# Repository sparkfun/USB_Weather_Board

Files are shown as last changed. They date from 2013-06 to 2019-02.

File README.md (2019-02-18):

# **NOTE: This product has been retired from our catalog. The information contained here is for reference only. No support is guaranteed. For a new version, please check out our [Weather Shield](https://www.sparkfun.com/products/12081).**

*If you are looking for more up-to-date info, please check out some of these resources to see how other users are still hacking and improving on this product.*
* *[SparkFun Forum](https://forum.sparkfun.com/)*
* *[Comments Here on GitHub](https://github.com/sparkfun/USB_Weather_Board/issues)*
* *[IRC Channel](https://www.sparkfun.com/news/263)*

## USB Weather Board [(SEN-10586)](https://www.sparkfun.com/products/10586)

USB Weather Board

SparkFun's USB Weather Board contains sensors that can be used to monitor atmospheric pressure, humidity, temperature, and light level. The board can also be interfaced to wind speed, direction, and rainfall sensors available separately from Sparkfun.

Product page: [www.sparkfun.com/products/10586](https://www.sparkfun.com/products/10586)

User guide: [https://github.com/sparkfun/USB_Weather\_Board/blob/master/USB\_Weather\_Board\_V3\_datasheet\_130705.pdf?raw=true](https://github.com/sparkfun/USB_Weather_Board/blob/master/USB_Weather_Board_V3_datasheet_130705.pdf?raw=true)

Github repository: [https://github.com/sparkfun/USB\_Weather\_Board](https://github.com/sparkfun/USB_Weather_Board)

This archive contains the latest sketch (firmware) that the USB Weather Board uses to sample the sensors and output data. You can use this sketch as-is, modify it to suit your own purposes, or write your own sketches from scratch. See the datasheet and schematics for more information.

### Installation:

If you haven't, install the free Arduino IDE, available at [www.arduino.cc](http://www.arduino.cc). This code was tested using Arduino versions 1.0.3, 1.0.4 and 1.0.5.

This sketch requires several nonstandard libraries (special device interface code):

* SHT15x by Jonathan Oxer et.al.
* SFE_BMP085 library by SparkFun
	
These libraries are included in this archive, and must be installed onto your computer in order for the code to compile correctly. See the instructions below.

#### Installing the required files:

TL;DR: The one-step procedure to install all of the required files is to drag the contents of the Arduino folder contained in this archive into your personal Arduino sketch folder (this is normally located in your personal documents folder.) This will create a "libraries" folder (containing the above libraries), and a "Weather\_Board\_3" folder containing the sketch.

If there is already a "libraries" folder, add the included libraries to it. If there are older versions of the above libraries in the folder, please replace them with the versions in this archive. If it is running, restart the Arduino IDE to get it to recognize the new libraries.

#### Loading the firmware onto your USB Weather Board:

1. Connect the USB Weather Board to your computer using a standard mini-B USB cable (available everywhere including www.sparkfun.com). Move both switches on the USB Weather Board to USB. The red LED should light up and your computer should automatically install the FTDI drivers and create a virtual COM port. If there is a problem installing the FTDI drivers, please see the instructions at www.arduino.cc.

2. Start the Arduino IDE.

3. Select the following board type from the Tools/Board menu: "Arduino Pro or Pro Mini (3.3V, 8MHz) w/ATmega328"

4. Select the correct serial port from the Tools/Serial Port menu. This will be the port that your FTDI board or cable has created, it is usually the highest numbered port in the list of options.

5. Load (up-arrow button) the weather\_board\_3.ino sketch into the Arduino IDE.

6. Click on the Upload (right arrow) button at the top of the window. The code should compile then upload to the USB Weather Board. If there are any errors, double-check that you installed the required libraries to the correct folder, and have restarted the Arduino IDE. If you continue to have problems, please contact SparkFun Technical Support (see the "Contact" section of www.sparkfun.com) and they'll be happy to help you get up and running.

Once the sketch is uploaded, the green LED will blink three times and the board will begin running. To check the output, you can use the terminal software of your choice, or open the Arduino IDE's Serial Monitor window (magnifying-glass button). Ensure that the Serial Monitor window is set to "9600 baud", and that line ending is set to "carriage return". To bring up the menu, type a 'Z' character into the entry box at the top of the window, and press send or hit return. See the datasheet for more information.

If you have questions, don't hesistate to contact us at techsupport@sparkfun.com.

Have fun!
Your friends at SparkFun.

### Revision history:

1.4 2013/7/5

> Changed all menu operations to completely support Arduino serial monitor (CR/NL ignored unless needed). Set Arduino serial monitor to 9600 baud, and line endings to carriage return.

1.3 2013/6/25

> Added code to prevent an intermittent lockup when rebooting; now resets the humidity sensor connection before intializing the BMP085. Many thanks to Nathan Isherwood.
		
> Added plain 'Z' and 'z' as well as CTRL-Z to enter menu to better support Arduino serial monitor.
		
> Fixed error in rain-gauge constant. Many thanks to Michael Bauer.

> Added reset to factory defaults option to menu.

> Moved constant strings to flash (freed over 1K bytes!)

1.2 2012/1/23

> Update all code to be compatible with Arduino 1.0
		
1.1 2011/08/01

> Changed sample_rate to 32-bit, max = 4294966 seconds (47 days)

> RAM is also getting tight, so removed some error strings and added RAM gauge to menu.
		
1.0 2011/06/27

> Initial release

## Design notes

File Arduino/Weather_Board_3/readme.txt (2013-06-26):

This firmware is for SparkFun's USB Weather Board version 3, which is located at https://www.sparkfun.com/products/10586.
It may not work for other versions of the hardware.

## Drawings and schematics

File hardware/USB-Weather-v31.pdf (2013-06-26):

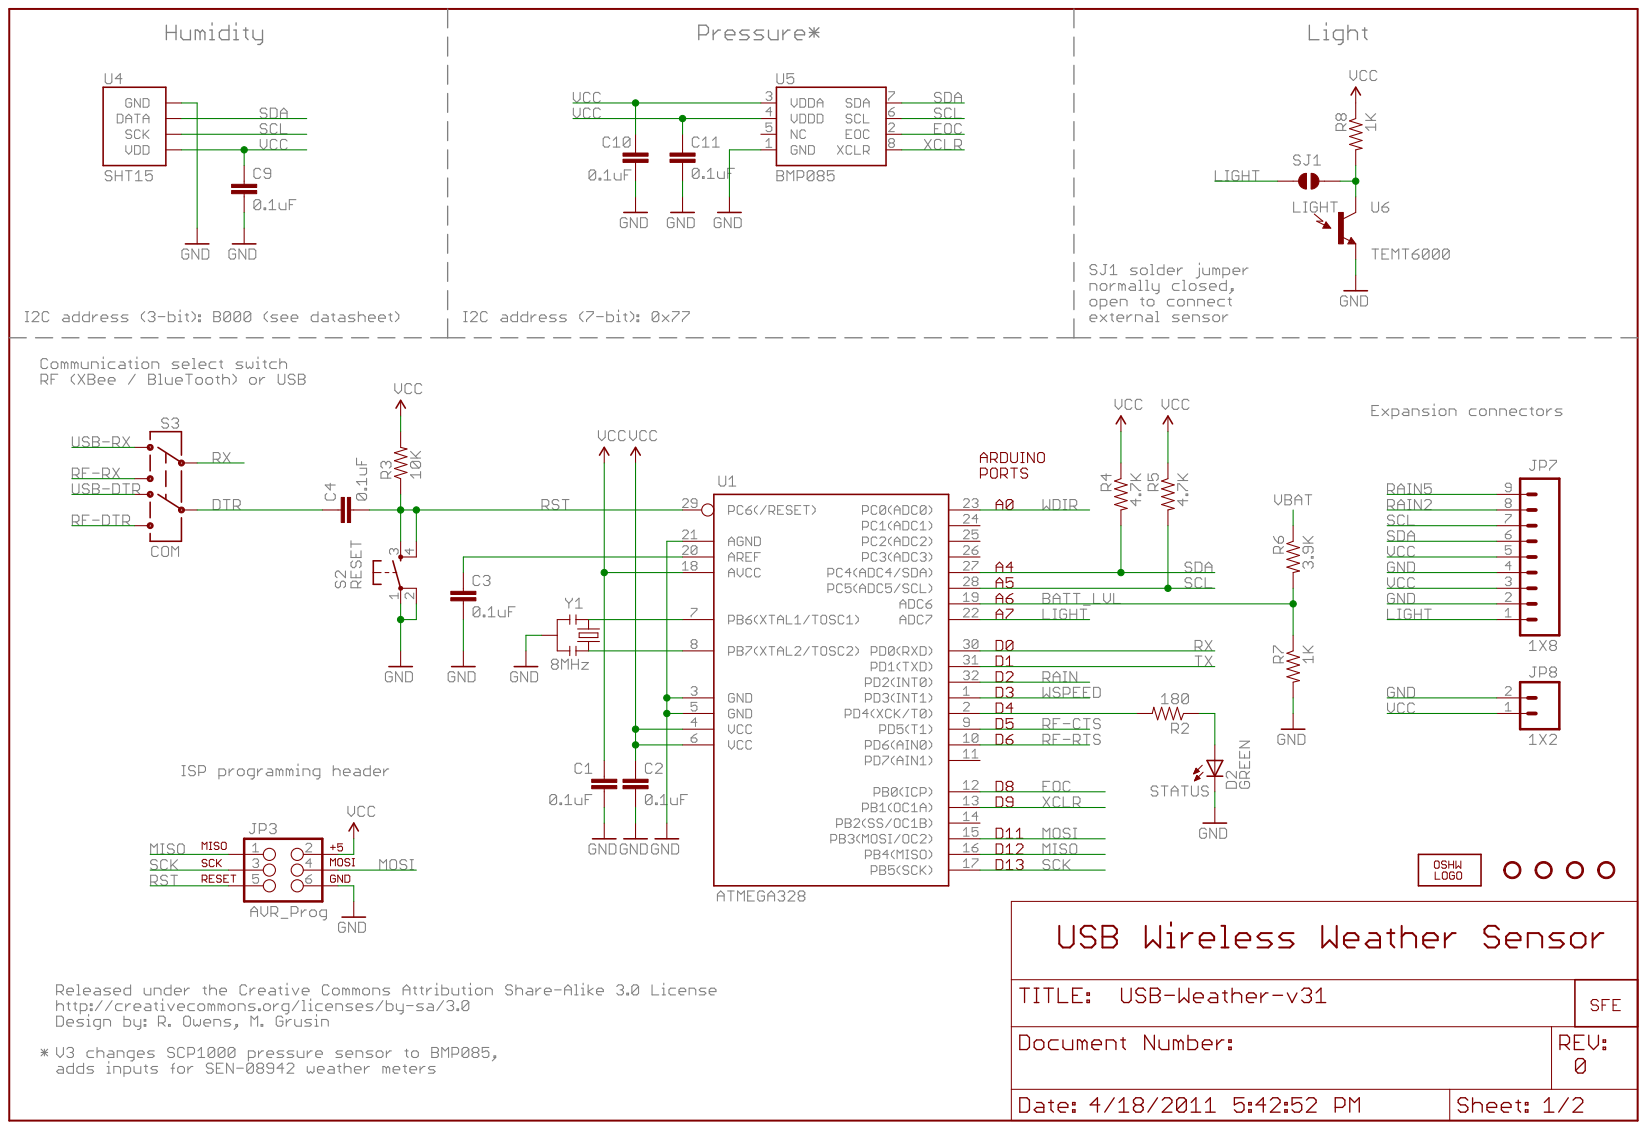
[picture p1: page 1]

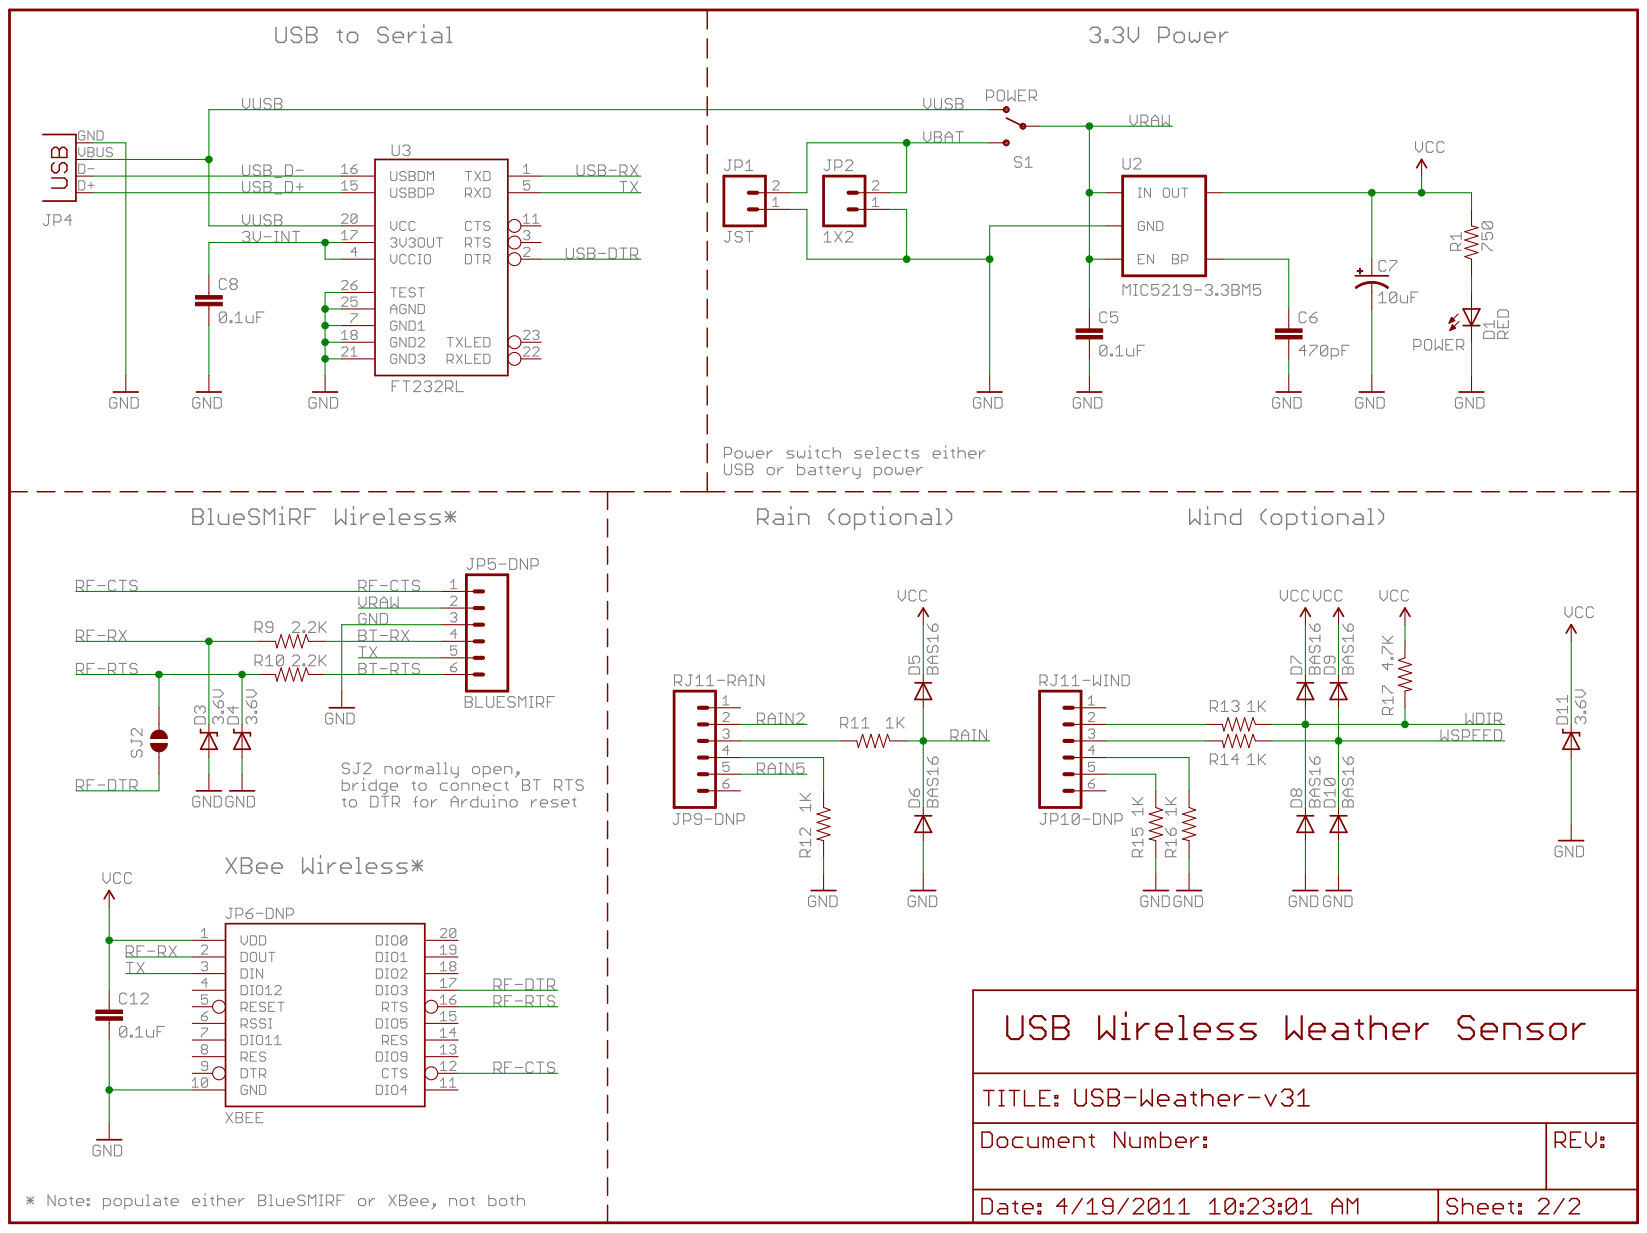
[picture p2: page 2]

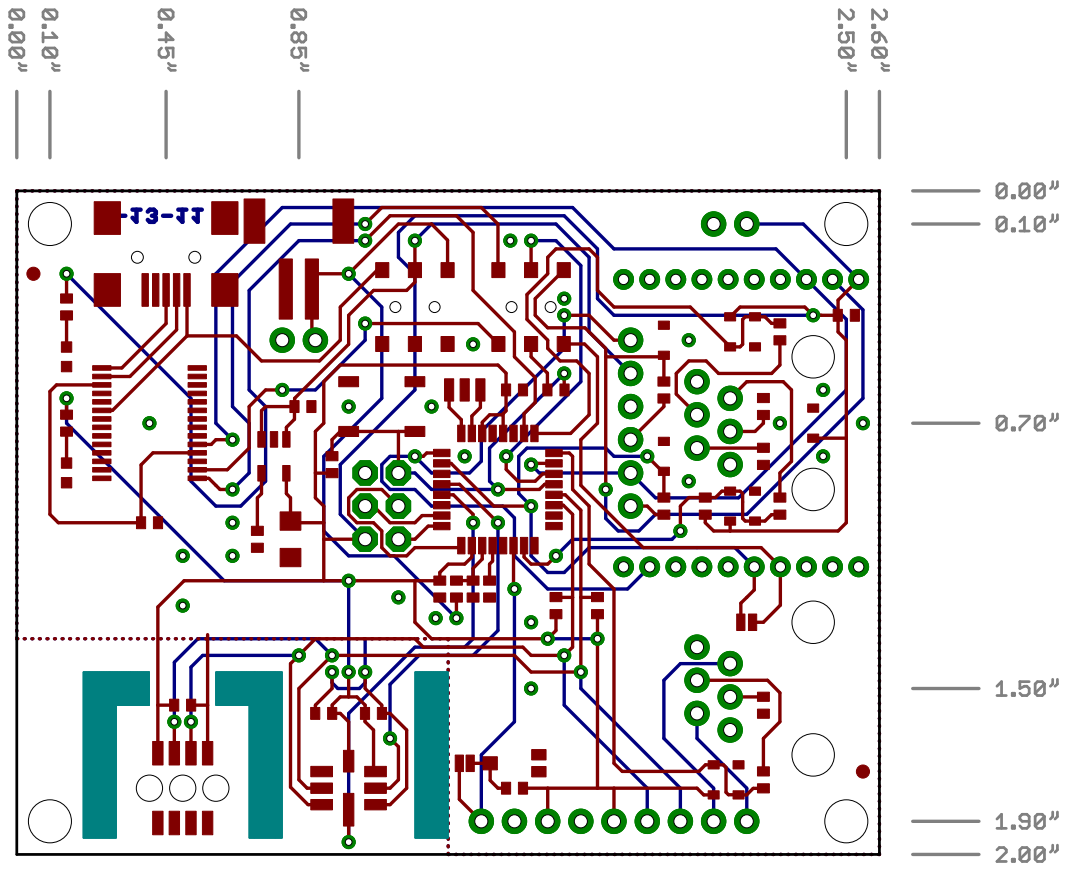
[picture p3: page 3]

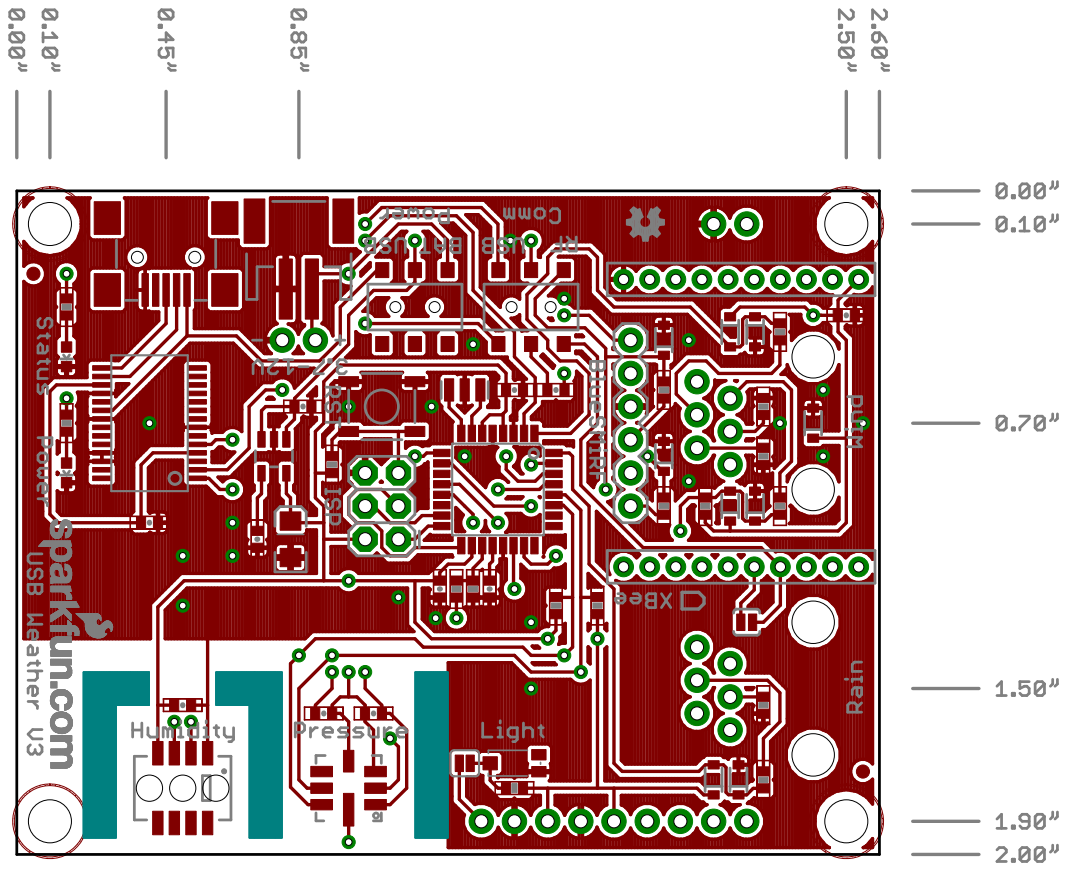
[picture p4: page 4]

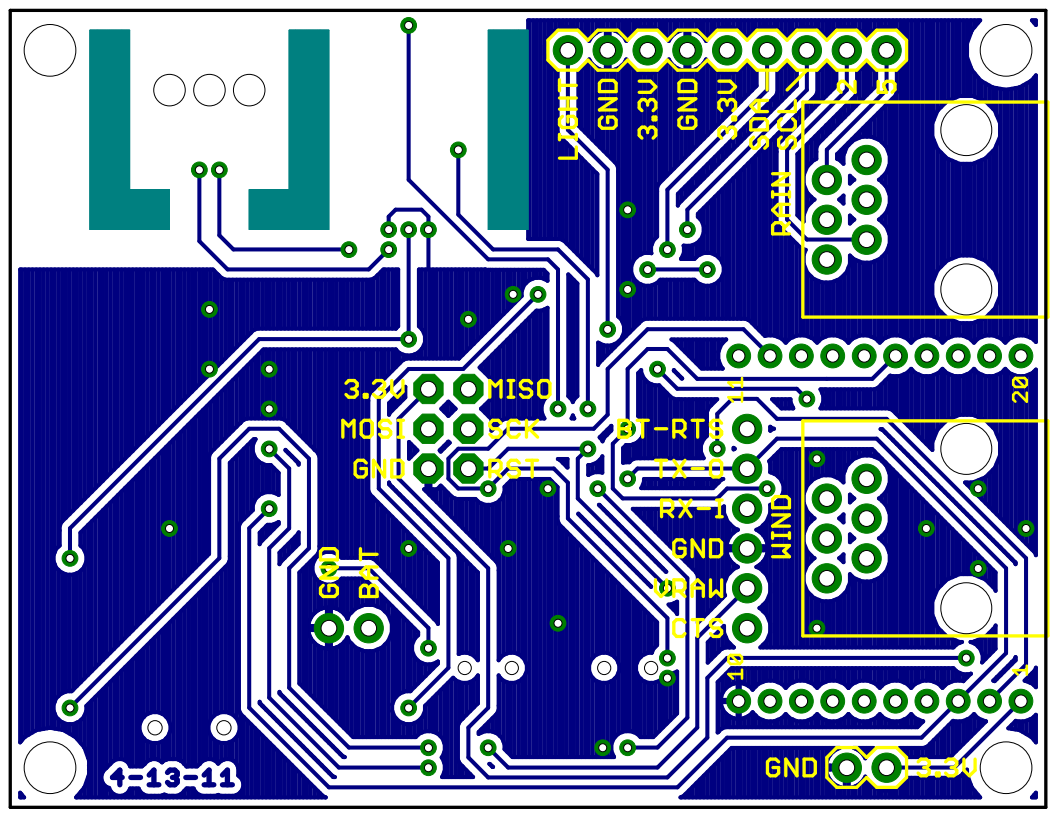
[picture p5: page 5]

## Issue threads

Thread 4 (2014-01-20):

Couple of things on the V40 fork

uChip, 2014-01-20:
Mike,
I sent you an email about a week ago but I didn't get a response so I don't know if it made it thru.  I noticed an issue with pin numbering on the v40 schematic.  On the 328 pins 13 & 14 are both labeled as Arduino Port D9.  Then in the notes it says that the status LED is on port D11 when the schematic shows that line labeled as D10.

Also, I like the direction of the new version but is there a way I can lobby for a couple of changes?
Thanks,
Chip

ToniCorinne, 2017-02-08:
Closing this issue out, as the current weather board has been retired. These notes have been copied over to our backend for future revisions of the Weather shield board.

Closed 2017-02-08.

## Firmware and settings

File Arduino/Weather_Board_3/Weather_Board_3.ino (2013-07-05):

// USB Weather Board V3 firmware
// Mike Grusin, SparkFun Electronics
// www.sparkfun.com

// Compile and load onto SparkFun USB Weather Board V3 using Arduino development envrionment,
// Download from www.arduino.cc

// Set Tools/Board to "Arduino Pro or Pro Mini (3.3V 8MHz) w/ ATmega328"

// To use the Arduino serial monitor to access the menu, set the serial
// monitor line ending to "Carriage Return" and speed to "9600 baud".

// Uses the SHT15x library by Jonathan Oxer et.al.  https://github.com/practicalarduino/SHT1x
// A special version is supplied with this software distribution.
// Place in your Arduino sketchbook under "libraries/SHT1x"

// Uses the SFE_BMP085 library by SparkFun with math from http://wmrx00.sourceforge.net/Arduino/BMP085-Calcs.pdf
// Supplied with this distribution; place in your Arduino sketchbook under "libraries/SFE_BMP085"

// License:
// This code is free to use, change, improve, even sell!  All we ask for is two things:
// 1. That you give SparkFun credit for the original code,
// 2. If you sell or give it away, you do so under the same license so others can do the same thing.
// More at http://creativecommons.org/licenses/by-sa/3.0/

// Have fun! 
// -your friends at SparkFun

// Revision history
// 1.4 2013/7/5
//     Changed all menu operations to completely support
//     Arduino serial monitor (CR/NL ignored unless needed).
// 1.3 2013/6/25
//     Added code to prevent an intermittent lockup when rebooting; 
//     now resets the humidity sensor connection before intializing
//     the BMP085. Many thanks to Nathan Isherwood.
//     Added plain 'Z' and 'z' as well as CTRL-Z to enter menu
//     to better support Arduino serial monitor.
//     Fixed error in rain-gauge constant. Many thanks to Michael Bauer.
//     Added reset to factory defaults option to menu.
//     Moved constant strings to flash (freed over 1K bytes!)
// 1.2 2012/1/23
//     Update all code to be compatible with Arduino 1.0
// 1.1 2011/08/01
//     Changed sample_rate to 32-bit, max = 4294966 seconds (47 days)
//     RAM is also getting tight, so removed some error strings and
//     added RAM gauge to menu.
// 1.0 2011/06/27
//     Initial release

// firmware version
const char version_major = 1;
const char version_minor = 4;

// external libraries
#include <SHT1x.h> // SHT15 humidity sensor library
#include <SFE_BMP085.h> // BMP085 pressure sensor library
#include <Wire.h> // I2C library (necessary for pressure sensor)
#include <avr/eeprom.h> // extended EEPROM read/write functions

// digital I/O pins
// (the following three are predefined)
// const int SCK = 13;
// const int MISO = 12;
// const int MOSI = 11;
const int XCLR = 9;
const int EOC = 8;
const int RF_RTS = 6;
const int RF_CTS = 5;
const int STATUSLED = 4;
const int WSPEED = 3;
const int RAIN = 2;

// analog I/O pins
const int LIGHT = 7;
const int BATT_LVL = 6;
const int WDIR = 0;

// global variables
float SHT15_humidity;
float SHT15_temp;
float SHT15_dewpoint;
double BMP085_pressure;
double BMP085_temp;
float TEMT6000_light;
float WM_wspeed;
float WM_wdirection;
float WM_rainfall = 0.0;
float batt_volts;
int LED = 0; // status LED
unsigned int windRPM, stopped;
// volatiles are subject to modification by IRQs
volatile unsigned long tempwindRPM, windtime, windlast, windinterval;
volatile unsigned char windintcount;
volatile boolean gotwspeed;
volatile unsigned long raintime, rainlast, raininterval, rain;

// constant conversion factors
const int BATT_RATIO = 63.3271; // divide ADC from BATT_LVL by this to get volts
const float WIND_RPM_TO_MPH = 22.686745; // divide RPM by this for velocity
const float WIND_RPM_TO_MPS = 50.748803; // divide RPM by this for meters per second
const float RAIN_BUCKETS_TO_INCHES = 0.014815; // multiply bucket tips by this for inches
const float RAIN_BUCKETS_TO_MM = 0.376296; // multiply bucket tips by this for mm 
const unsigned int ZERODELAY = 4000; // ms, zero RPM if no result for this time period (see irq below)

// sensor objects
SHT1x humidity_sensor(A4, A5);
SFE_BMP085 pressure_sensor(BMP_ADDR);

// enumerated options, changed in user menu

// output format
const int CSV = 1; // default NMEA-like comma-separated values
const int ANSI = 2; // ANSI-formatted data with hardware testing
const int LCD = 3; // directly drive a SparkFun serial-enabled 16x2 LCD display

// general units
const int ENGLISH = 1; // wind speed in miles per hour, rain in inches, temperature in degrees Fahrenheit
const int SI = 2; // International System, aka the metric system. Wind speed in meters per second, rain in mm, temperature in degrees Celsius

// pressure units
const int MBAR = 1; // millibars
const int INHG = 2; // inches of mercury (US weather report standard)
const int PSI = 3; // pounds per square inch

// pressure type
const int ABSOLUTE = 1; // absolute (true) pressure, changes with altitude (ignore altitude variable)
const int RELATIVE = 2; // relative (weather) pressure, altitude effects removed (use altitude variable)

// defaults, replaced with EEPROM settings if saved
int data_format = ANSI;
int general_units = ENGLISH;
unsigned long sample_rate = 2; // sample rate (seconds per sample, 0 for as fast as possible)
int pressure_type = RELATIVE;
long altitude = 1596; // fixed weather station altitude in meters, for relative (sea level) pressure measurement
int pressure_units = INHG;
boolean weather_meters_attached = true; // true if we've hooked up SparkFun's Weather Meters (SEN-08942) (set to false to remove weather meters data from output)
long baud_rate = 9600; // default baud rate

// hardware memory pointers, used by freeMemory() (see: http://www.arduino.cc/playground/Code/AvailableMemory)

extern unsigned int __bss_end;
extern unsigned int __heap_start;
extern void *__brkval;

int freeMemory()
{
  int free_memory;

  if((int)__brkval == 0)
     free_memory = ((int)&free_memory) - ((int)&__bss_end);
  else
    free_memory = ((int)&free_memory) - ((int)__brkval);

  return free_memory;
}

// interrupt routines (these are called by the hardware interrupts, not by the main code)

void rainIRQ()
// if the Weather Meters are attached, count rain gauge bucket tips as they occur
// activated by the magnet and reed switch in the rain gauge, attached to input D2
{
  raintime = micros(); // grab current time
  raininterval = raintime - rainlast; // calculate interval between this and last event

  if (raininterval > 100) // ignore switch-bounce glitches less than 100uS after initial edge
  {
    rain++; // increment bucket counter
    rainlast = raintime; // set up for next event
  }
}

void wspeedIRQ()
// if the Weather Meters are attached, measure anemometer RPM (2 ticks per rotation), set flag if RPM is updated
// activated by the magnet in the anemometer (2 ticks per rotation), attached to input D3

// this routine measures RPM by measuring the time between anemometer pulses
// windintcount is the number of pulses we've measured - we need two to measure one full rotation (eliminates any bias between the position of the two magnets)
// when windintcount is 2, we can calculate the RPM based on the total time from when we got the first pulse
// note that this routine still needs an outside mechanism to zero the RPM if the anemometer is stopped (no pulses occur within a given period of time)
{
  windtime = micros(); // grab current time
  if ((windintcount == 0) || ((windtime - windlast) > 10000)) // ignore switch-bounce glitches less than 10ms after the reed switch closes
  {
    if (windintcount == 0) // if we're starting a new measurement, reset the interval
      windinterval = 0;  
    else
      windinterval += (windtime - windlast); // otherwise, add current interval to the interval timer

    if (windintcount == 2) // we have two measurements (one full rotation), so calculate result and start a new measurement
    {
      tempwindRPM = (60000000ul / windinterval); // calculate RPM (temporary since it may change unexpectedly)
      windintcount = 0;
      windinterval = 0;  
      gotwspeed = true; // set flag for main loop
    }

    windintcount++;    
    windlast = windtime; // save the current time so that we can calculate the interval between now and the next interrupt
  }
}

void setup()
// this procedure runs once upon startup or reboot
// perform all the settings we need before running the main loop
{
  // set up inputs and outputs
  pinMode(XCLR,OUTPUT); // output to BMP085 reset (unused)
  digitalWrite(XCLR,HIGH); // make pin high to turn off reset 
  
  pinMode(EOC,INPUT); // input from BMP085 end of conversion (unused)
  digitalWrite(EOC,LOW); // turn off pullup
  
  pinMode(STATUSLED,OUTPUT); // output to status LED
  
  pinMode(WSPEED,INPUT); // input from wind meters windspeed sensor
  digitalWrite(WSPEED,HIGH); // turn on pullup
  
  pinMode(RAIN,INPUT); // input from wind meters rain gauge sensor
  digitalWrite(RAIN,HIGH); // turn on pullup

  // get settings from EEPROM (use defaults if EEPROM has not been used)
  retrieveEEPROMsettings();
 
  // initialize serial port
  Serial.begin(baud_rate);
  Serial.println();
  Serial.println(F("RESET"));
  
  // Reset the humidity sensor connection so that the I2C bus can be accessed
  TWCR &= ~(_BV(TWEN)); // turn off I2C enable bit so we can access the SHT15 humidity sensor 
  digitalWrite(XCLR,LOW); // disable the BMP085 while resetting humidity sensor
  humidity_sensor.connectionReset(); // reset the humidity sensor connection
  TWCR |= _BV(TWEN); // turn on I2C enable bit so we can access the BMP085 pressure sensor
  digitalWrite(XCLR,HIGH); // enable BMP085
  delay(10); // wait for the BMP085 pressure sensor to become ready after reset
  
  // initialize BMP085 pressure sensor
  if (pressure_sensor.begin() == 0)
    error(1);

  // init wind speed interrupt global variables
  gotwspeed = false; windRPM = 0; windintcount = 0;
 
  // blink status LED 3 times
  digitalWrite(STATUSLED,HIGH);
  delay(100);
  digitalWrite(STATUSLED,LOW);
  delay(250);
  digitalWrite(STATUSLED,HIGH);
  delay(100);
  digitalWrite(STATUSLED,LOW);
  delay(250);
  digitalWrite(STATUSLED,HIGH);
  delay(100);
  digitalWrite(STATUSLED,LOW);
  delay(250);

  if (weather_meters_attached)
  {
    // attach external interrupt pins to IRQ functions
    attachInterrupt(0,rainIRQ,FALLING);
    attachInterrupt(1,wspeedIRQ,FALLING);
    
    // turn on interrupts
    interrupts();
  }
}

void loop()
// loops forever after setup() ends
{
  static long templong, windstopped;
  static unsigned long loopstart, loopend;
  double Tn, m;
  static char LCDstate;
  char status;
  
  // record current time so we can sample at regular intervals
  loopstart = millis();
  loopend = loopstart + (sample_rate * 1000ul);

  // turn on LED while we're doing measurements
  digitalWrite(STATUSLED,HIGH);

  // an interrupt occurred, handle it now
  if (gotwspeed)
  {
    gotwspeed = false;
    windRPM = word(tempwindRPM); // grab the RPM value calculated by the interrupt routine
    windstopped = millis() + ZERODELAY; // save this timestamp
  }

  // zero wind speed RPM if we don't get a reading in ZERODELAY ms
  if (millis() > windstopped)
  {
    windRPM = 0; windintcount = 0;
  }
  
  TWCR &= ~(_BV(TWEN));  // turn off I2C enable bit so we can access the SHT15 humidity sensor

  // get humidity and temp (SHT15)
  SHT15_temp = humidity_sensor.readTemperatureC();
  SHT15_humidity = humidity_sensor.readHumidity();

  // compute dewpoint (because we can!)
  if (SHT15_temp > 0.0)
    {Tn = 243.12; m = 17.62;}
  else
    {Tn = 272.62; m = 22.46;}

  SHT15_dewpoint = (Tn*(log(SHT15_humidity/100)+((m*SHT15_temp)/(Tn+SHT15_temp)))/(m-log(SHT15_humidity/100)-((m*SHT15_temp)/(Tn+SHT15_temp))));

  // get temp (SHT15)
  switch (general_units)
  {
    case ENGLISH: // Fahrenheit
      SHT15_temp = (SHT15_temp*9.0/5.0)+32.0;
      SHT15_dewpoint = (SHT15_dewpoint*9.0/5.0)+32.0;
      break;
    case SI: // celsius, don't need to do anything
      break;
    default:
      SHT15_temp = -1.0; // error, invalid units
      SHT15_dewpoint = -1.0; // error, invalid units
  }

  TWCR |= _BV(TWEN);  // turn on I2C enable bit so we can access the BMP085 pressure sensor

  // start BMP085 temperature reading
  status = pressure_sensor.startTemperature();
  if (status != 0)
    delay(status); // if nonzero, status is number of ms to wait for reading to become available
  else
    error(2);
    
  // retrieve BMP085 temperature reading
  status = pressure_sensor.getTemperature(&BMP085_temp); // deg C
  if (status == 0)
    error(3);
  
  // start BMP085 pressure reading
  status = pressure_sensor.startPressure(3);
  if (status != 0)
    delay(status); // if nonzero, status is number of ms to wait for reading to become available
  else
    error(4);
    
  // retrieve BMP085 pressure reading
  status = pressure_sensor.getPressure(&BMP085_pressure, &BMP085_temp); // mbar, deg C
  if (status == 0)
    error(5);
 
  // compensate for altitude if needed
  if (pressure_type == RELATIVE)
    BMP085_pressure = pressure_sensor.sealevel(BMP085_pressure,altitude);

  // convert to desired units
  switch (general_units)
  {
    case SI: // celsius
      // do nothing, already C
      break;
    case ENGLISH: // Fahrenheit
      BMP085_temp = BMP085_temp * 1.8 + 32.0;
      break;
    default:
      BMP085_temp = -1.0; // error, invalid units
  }

  switch (pressure_units)
  {
    case MBAR:
      // do nothing, already mbar
      break;
    case INHG:
      BMP085_pressure = BMP085_pressure / 33.8600000;
      break;
    case PSI:
      BMP085_pressure = BMP085_pressure / 68.9475728;
      break;
    default:
      BMP085_pressure = -1.0; // error, invalid units
  }

  // get light
  TEMT6000_light = (1023.0 - float(analogRead(LIGHT))) / 10.23; // 0-100 percent

  // windspeed unit conversion
  switch (general_units)
  {
    case SI: // meters per second
      WM_wspeed = float(windRPM) / WIND_RPM_TO_MPS;
      break;
    case ENGLISH: // miles per hour
      WM_wspeed = float(windRPM) / WIND_RPM_TO_MPH;
      break;
    default:
      WM_wspeed = -1.0; // error, invalid units
  }

  // get wind direction
  WM_wdirection = get_wind_direction();

  // rainfall unit conversion
  switch (general_units)
  {
    case SI: // mm
      WM_rainfall = rain * RAIN_BUCKETS_TO_MM;
      break;
    case ENGLISH: // inches
      WM_rainfall = rain * RAIN_BUCKETS_TO_INCHES;
      break;
    default:
      WM_rainfall = -1.0; // error, invalid units
  }

  // get battery voltage
  batt_volts = float(analogRead(BATT_LVL)) / BATT_RATIO;

  // below are a bunch of nested switch statements to handle the different output data_formats that are possible
  // feel free to modify them or add your own!

  switch (data_format)
  {

    case CSV: // data_format: comma-separated values
    {
      // number after values is number of digits after decimal point to print
      Serial.print(F("$"));
      printComma();
      Serial.print(SHT15_temp,1);
      printComma();
      Serial.print(SHT15_humidity,0);
      printComma();
      Serial.print(SHT15_dewpoint,1);
      printComma();
      switch (pressure_units) // change decimal point for different units
      {
        case MBAR:
          Serial.print(BMP085_pressure,2);
          break;
        case INHG:
          Serial.print(BMP085_pressure,3);
          break;
        case PSI:
          Serial.print(BMP085_pressure,4);
          break;
      }
      printComma();
      // Serial.print(BMP085_temp,1);  // for CSV format, we'll only output the SHT15 temperature
      // Serial.print(F(","));
      Serial.print(TEMT6000_light,1);
      printComma();
      if (weather_meters_attached)
      {
        Serial.print(WM_wspeed,1);
        printComma();
        Serial.print(WM_wdirection,0);
        printComma();
        switch (general_units) // change decimal point for different units
        {
          case ENGLISH:
            Serial.print(WM_rainfall,2);
            break;
          case SI:
            Serial.print(WM_rainfall,1);
            break;
        }
        printComma();
      }
      Serial.print(batt_volts,2);
      printComma();
      Serial.print(F("*"));
      Serial.println();
    }
    break;

    case ANSI: // this data_format neatly formats the data on an ANSI terminal, and has pass/fail values for testing
    {
      ansiHome();
      Serial.println();
  
      Serial.print(F("SHT15 temperature:"));
      ansiTab();
      ansiTab();
      Serial.print(SHT15_temp,1);
      Serial.print(F(" deg "));
      switch (general_units)
      {
        case ENGLISH:
          Serial.print(F("F "));
          ansiTab();
          if ((SHT15_temp > 60) && (SHT15_temp < 85)) pass(); else fail();
          break;
        case SI:
          Serial.print(F("C "));
          ansiTab();
          if ((SHT15_temp > 15) && (SHT15_temp < 30)) pass(); else fail();
          break;
      }

      Serial.print(F("SHT15 humidity:  "));
      ansiTab();
      ansiTab();
      Serial.print(SHT15_humidity,0);
      Serial.print(F("% "));
      ansiTab();
      ansiTab();
      if ((SHT15_humidity > 10) && (SHT15_humidity < 90)) pass(); else fail();


      Serial.print(F("SHT15 dewpoint:  "));
      ansiTab();
      ansiTab();
      Serial.print(SHT15_dewpoint,1);
      Serial.print(F(" deg "));
      switch (general_units)
      {
        case ENGLISH:
          Serial.println(F("F "));
          break;
        case SI:
          Serial.println(F("C "));
          break;
      }

      Serial.print(F("BMP085 pressure:"));
      ansiTab();
      ansiTab();
      switch (pressure_units) // change decimal point for different units
      {
        case MBAR:
          Serial.print(BMP085_pressure,2);
          Serial.print(F(" mbar "));
          ansiTab();
          if ((BMP085_pressure > 900) && (BMP085_pressure < 1100)) pass(); else fail();
          break;
        case INHG:
          Serial.print(BMP085_pressure,3);
          Serial.print(F(" in Hg "));
          ansiTab();
          if ((BMP085_pressure > 25) && (BMP085_pressure < 35)) pass(); else fail();
          break;
        case PSI:
          Serial.print(BMP085_pressure,4);
          Serial.print(F(" PSI "));
          ansiTab();
          if ((BMP085_pressure > 13) && (BMP085_pressure < 15)) pass(); else fail();
          break;
      }

      Serial.print(F("BMP085 temperature:"));
      ansiTab();
      ansiTab();
      Serial.print(BMP085_temp,1);
      Serial.print(F(" deg "));
      switch (general_units)
      {
        case ENGLISH:
          Serial.print(F("F "));
          ansiTab();
          if ((BMP085_temp > 60) && (BMP085_temp < 90)) pass(); else fail();
          break;
        case SI:
          Serial.print(F("C "));
          ansiTab();
          if ((BMP085_temp > 15) && (BMP085_temp < 35)) pass(); else fail();
          break;
      }
  
      Serial.print(F("TEMT6000 light:  "));
      ansiTab();
      ansiTab();
      Serial.print(TEMT6000_light,1);
      Serial.print(F("% "));
      ansiTab();
      ansiTab();
      if ((TEMT6000_light > 0) && (TEMT6000_light < 100)) pass(); else fail();
  
      if (weather_meters_attached)
      {
        Serial.print(F("Weather meters wind speed:"));
        ansiTab();
        Serial.print(WM_wspeed,1);
        switch (general_units)
        {
          case ENGLISH:
            Serial.print(F(" MPH "));
            ansiTab();
            if (WM_wspeed > 0.0) pass(); else fail();
            break;
          case SI:
            Serial.print(F(" m/s "));
            ansiTab();
            ansiTab();
            if (WM_wspeed > 0.0) pass(); else fail();
            break;
        }
    
        Serial.print(F("Weather meters wind direction:"));
        ansiTab();
        Serial.print(WM_wdirection,0);
        Serial.print(F(" degrees "));
        ansiTab();
        // direction will read -1 if wind direction sensor is disconnected or faulty
        if (WM_wdirection != -1) pass(); else fail();
    
        Serial.print(F("Weather meters rainfall:"));
        ansiTab();
        switch (general_units)
        {
          case ENGLISH:
            Serial.print(WM_rainfall,2);
            Serial.print(F(" inches "));
            ansiTab();
            if (WM_rainfall > 0.05) pass(); else fail();
            break;
          case SI:
            Serial.print(WM_rainfall,0);
            Serial.print(F(" mm "));
            ansiTab();
            ansiTab();
            if (WM_rainfall > 0.5) pass(); else fail();
            break;
        }
      }
      Serial.print(F("External power:  "));
      ansiTab();
      ansiTab();
      Serial.print(batt_volts,2);
      Serial.print(F(" Volts "));
      ansiTab();
      if ((batt_volts > 3.5) && (batt_volts < 13.0)) pass(); else fail();
      Serial.println();
    }
    break;
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

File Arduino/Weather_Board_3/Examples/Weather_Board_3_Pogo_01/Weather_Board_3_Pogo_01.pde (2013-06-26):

// digital I/O pins
const int RAIN3 = 4;
const int RAIN4 = 5;
const int WIND3 = 6;
const int WIND4 = 7;
const int STATUS = A1;

void setup() 
{
  // make pins inputs first
  pinMode(RAIN3,INPUT);
  digitalWrite(RAIN3,LOW); // turn off pullup
  pinMode(RAIN4,INPUT);
  digitalWrite(RAIN4,LOW); // turn off pullup
  pinMode(WIND3,INPUT);
  digitalWrite(WIND3,LOW); // turn off pullup
  pinMode(WIND4,INPUT);
  digitalWrite(WIND4,LOW); // turn off pullup

  pinMode(STATUS,OUTPUT);
}

void loop()
{
  // make pins outputs / low
  pinMode(RAIN3,OUTPUT);
  digitalWrite(RAIN3,LOW);
  pinMode(RAIN4,OUTPUT);
  digitalWrite(RAIN4,LOW);
  pinMode(WIND3,OUTPUT);
  digitalWrite(WIND3,LOW);
  pinMode(WIND4,OUTPUT);
  digitalWrite(WIND4,LOW);

  digitalWrite(STATUS,HIGH);

  delay(10);

  // make pins high-Z (disconnected)
  pinMode(RAIN3,INPUT);
  pinMode(RAIN4,INPUT);
  pinMode(WIND3,INPUT);
  pinMode(WIND4,INPUT);

  digitalWrite(STATUS,LOW);

  delay(90);
}

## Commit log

2013-06-26 Initial commit, hardware V31, firmware V12
    [USB-Weather-v31.brd, USB-Weather-v31.sch]
2013-06-27 Multiple changes to firmware V1.3
    Fix for intermittent lockup on startup (Isherwood)
    Fixed error in rain gauge constant (Bauer)
    Additional characters to get to menu (Z,z,CTRL-Z) to better support
    Arduino serial monitor (no CTRL chars).
    Changed extension from .pde to .ino
    Updated readmes and datasheet
    [Weather_Board_3.ino, Weather_Board_3_Pogo_01.pde]
2013-07-01 Initial testing and bug fixes
    Reset issue has not reappeared (report if it does)
    Added 'R' menu option to Reset to factory defaults
    (does not automatically save values to EEPROM, can
    Save afterwards if desired)
    Placed all string constants in Flash, saved 1K RAM!
    [Weather_Board_3.ino]
2013-07-05 Firmware V1.4
    Now completely compatible with the Arduino IDE's Serial Monitor window.
    (Ignores unneeded CR/LF characters). Be sure to set Serial Monitor
    window line ending to "carriage return" (dropdown option at bottom of
    window).
